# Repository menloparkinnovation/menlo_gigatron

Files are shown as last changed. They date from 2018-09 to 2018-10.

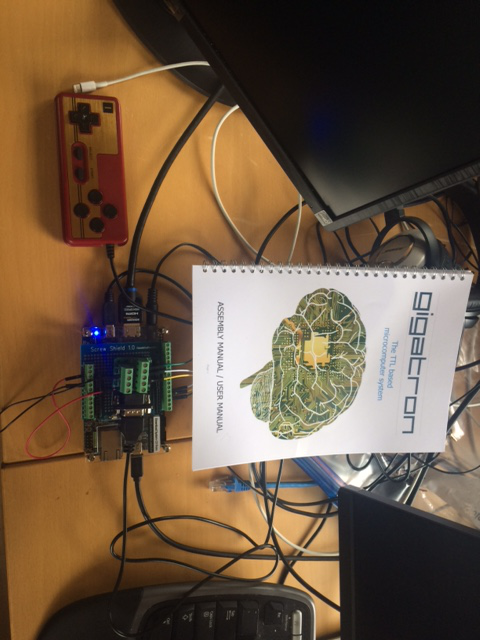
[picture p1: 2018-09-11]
pictures/hardware_wiring.jpg

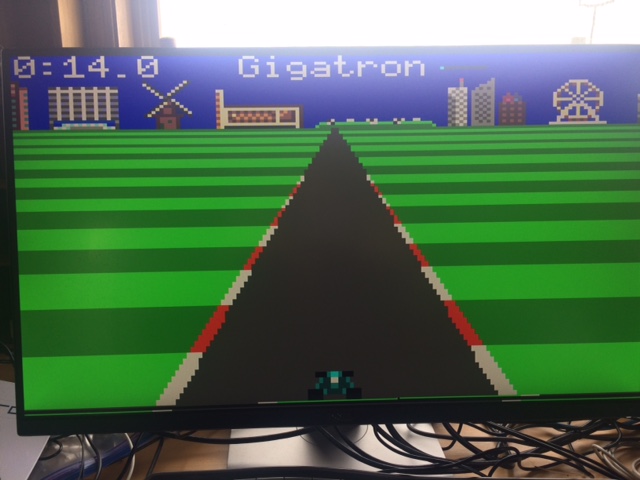
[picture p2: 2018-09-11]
pictures/racer_hires.jpg

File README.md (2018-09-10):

# menlo_gigatron
A System Verilog/FPGA implementation of the Gigatron project from https://gigatron.io/

# Building
Acquire a Terasic DE10-Nano FPGA development board from http://www.terasic.com.tw/cgi-bin/page/archive.pl?Language=English&CategoryNo=205&No=1046

It is about $130 retail, lower prices for education.

Other boards will work, but would need tweaking of the boards default "Shell" project that defines the resources of the board, and the specific version of the FPGA.

A Cyclone V SoC FPGA is used which as 41K logic elements and 5Mbits of block RAMS. It also has two 800Mhz ARM A9 processors with 1GB of RAM, and a couple of embedded Linux ports for both text mode and GUI. The SoC's are not currently used by this project at this time, but in the future will be used to manage downloads to the Gigatron and provide for an "EPROM emulator" for development.

Since its written in System Verilog, it could be ported to other FPGA's such as Xilinx.

The DE10-Nano user manual has instructions for installing the Altera/Intel Quartus II development software for the FPGA, which is available for free for educational and maker use. This software is required to compile your own FPGA bitstream from the Verilog sources.

# Running
The project implements an HDMI monitor interface with HDMI audio. The Gigatron's 4 bit VGA output and 4 bit sound is converted to 8 bit Truecolor at 640x480 on the monitor, with 16 bit I2S LPCM sound at 48Khz. The logic to do this actually exceeds the Gigatrons logic conumption by multiple times.

The Famicom game controller is connected with direct wires to the Arduino I/O pins on the DE10-Nano. The FPGA I/O ports have been configured to operate without the pull up or 68 ohm series resistors. I used a screw type DB9 male adapter and an Arduino "screw shield" for prototyping.

# Arduino IO Wiring
ARDUINO DIO2 - DB9 Pin 2 famicom_data (input)
ARDUINO DIO3 - DB9 Pin 4 famicom_pulse (output)
ARDUINO DIO4 - DB9 Pin 3 famicom_latch (output)
ARDUINO 5V   - DB9 Pin 6
ARDUINO GND  - DB9 Pin 8

# Future Work
Future work will provide an interface from the SoC's to the Gigatron to allow for development and debugging. This will include an emulation of the Arduino based loader for loading GTL programs into RAM, an EPROM emulator to allow Gigatron ROM development, and an ICE interface to read/write Gigatron registers and RAM, start/stop, etc. This would be available over character mode or VNC Linux running on the ARM SoC's.

The VGA framebuffer will be made available to the Linux, so an integration with a GUI Linux could be done within an X windows system with an application, and a merging of the Gigatron VGA handler in the project and the FPGA implementation of the Linux framebuffer.

# Gigatron Extensions
This provides a great platform for Gigatron extensions and experimentation. Additional registers, addressing modes, etc. I have thought of adding an extended addressing unit to it to allow it to access system memory outside of the Gigatron RAM so it can act as a soft processor. But this is challenged by having to manipulate 32 bit (or 64 bit addresses within a PCI bus) which involve many Gigatron processor load cycles. One solution would be to extend the register and instruction widths, but core Gigatron compatibility is still required. So we are back at 8080 -> 8086 -> 80286 -> 80386 -> ... all over again. One of the most fun aspects of the Gigatron project itself :-)

# Why did I do this?
I have an interest in FPGA based domain specific soft processors for my other project menlo_cnc which is an FPGA based CNC machine tool controller. Right now it operates similar to Gigatron as a simple microcoded hardware machine, but I want to add real time complex calculations such as curves onto the FPGA, and find that the interface to the ARM SoC's to be too slow. The Gigatron was used a learning experience in the implementation of a soft processor from scratch that could run existing software and tool chains, and do something useful and cool as well, such as play games.

I am a radio ham as well, and look forward to building an FPGA/SoC based implementation of a small portable SDR ham radio similar to, but an improvement on the excellent Elecraft KX3 (which I own). So I am interested in FPGA/SoC DSP techniques which is a leading area of SDR (Software Defined Radio).

On the professional side I am interested in Cloud applications of FPGA's at both the hyper-scale infrastructure, and Cloud applications such as "Big Data" and "AI". FPGA's have already revolutionized HFT (High Frequency Trading), and are emerging as a platform for drug discovery, etc. Soft processors on FPGA's are a solution to the slowing down of Moores law, which will have industry wide impact on the costs of computation. I anticipate future FPGA's to be tightly integrated with processors and to have complex programmable logic blocks similar to GPU's and DSP chips which allow a specific application domain to code its algorithms into the structure of the processor, with task specific data and operations as the "software".

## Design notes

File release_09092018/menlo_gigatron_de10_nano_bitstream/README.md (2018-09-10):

# FPGA Bitstream for DE10-Nano SoC and Cyclone V SoC FPGA.
Note that FPGA bitstreams are very specific to the board and FPGA version. If yours differs, a recompilation from the Verilog sources using Quartus II is required.

This bitstream may be loaded using the Altera loader JTAG loader utility without having to recompile the project.

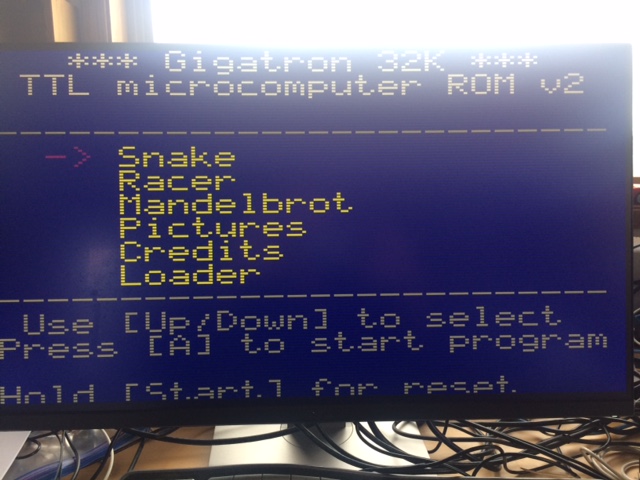
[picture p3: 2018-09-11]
pictures/signon.jpg

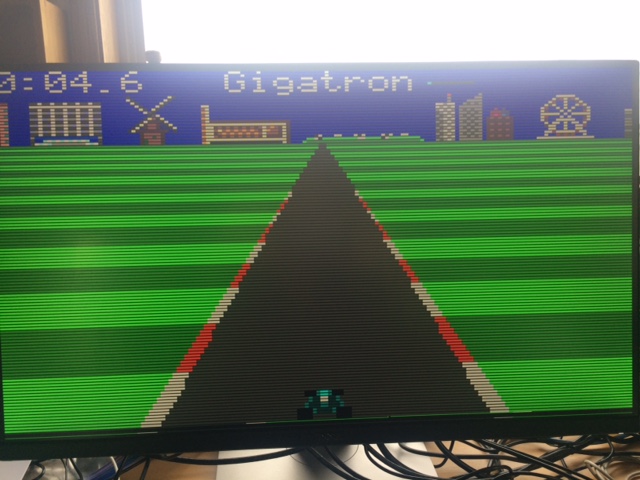
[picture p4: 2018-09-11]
pictures/racer_retro.jpg

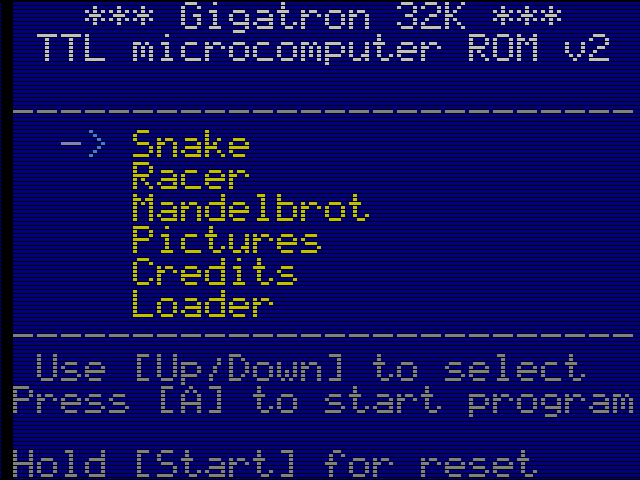
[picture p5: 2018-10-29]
menlo_gigatron_de10_nano/application_gigatron/first_full_screen.bmp

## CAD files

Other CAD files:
menlo_gigatron_de10_nano/db/stp1_auto_stripped.stp
menlo_gigatron_de10_nano/stp1.stp
archive/menlo_gigatron_de10_nano/db/stp1_auto_stripped.stp
archive/menlo_gigatron_de10_nano/stp1.stp

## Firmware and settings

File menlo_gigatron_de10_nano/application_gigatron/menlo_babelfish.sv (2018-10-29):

//
// TODO: 
//
// 10/10/2018
//
//  - remove loader_checksum as it operates on running_checksum now.
//

//
// See MENLO_COPYRIGHT.TXT for the copyright notice for this file.
//
// Use of this file is not allowed without the copyright notice present
// and re-distributed along with these files.
//

// set timescale for 1ns with 100ps precision.
`timescale 1ns / 100ps

//
// Gigatron BabelFish protocol implemented in System Verilog modeled
// on RDMA.
//
// Normally BabelFish runs on an Arduino, and its source code
// is in the Gigatron Rom Git project at:
//
// https://github.com/kervinck/gigatron-rom/Utils/BabelFish/babelfish.ino
//
// In this case BabelFish is implemented in System Verilog and is
// used by the Gigatron option ROM loader.
//
// Since the BabelFish loader protocol is essentially a version of RDMA
// (Remote Direct Memory Access), it will be modeled as such. This makes
// this Verilog code useful for other projects, such as network connected
// FPGA's for Software Defined Radio (SDR), machine tools (CNC), storage,
// and FPGA assisted high speed network communications between applications.
//
// FUTURE WORK:
//
//  Can generalize this RDMA communications handler by:
//
//  Add an IOMMU module to the output addresses. This will allow
//  address translation, validation, scatter/gather support, as
//  well as translations to program/VM virtual addresses based on
//  platform.
// 
//  Have the link level byte stream module interface be supplied to the
//  RDMA transmitter/receiver rather than contained within. This will allow
//  packet oriented protocols such as ethernet, UDP/IP/TCP to be readily
//  swapped in and out.
//
//  Have the RDMA framer modules interface be provided to the RDMA
//  transmitter/receiver. This allows other formats to be utilized
//  such as Infiniband or system TCP direct data placement.
//

module menlo_babelfish_rdma_transmitter
(
    input fpga_clock,      // FPGA 50Mhz clock
    input gigatron_clock,  // 6.25 Mhz Gigatron clock
    input reset,           // Reset when == 1

    // Timing input from the Gigatron
    input  famicom_pulse, // hsync_n
    input  famicom_latch, // vsync_n

    // Output to the Gigatron generated by this module
    output famicom_data,

    // Signals from user interface to select program to load
    input  request,  // true when user select load
    output request_ack, // true when transfer is complete.

    //
    // This provides access to the program loader option ROM.
    // rom_address == 0 is that start of the GT1 binary program
    // to load, as the invoker handles any translation from the base
    // 0 rom_address here to the offset into the option ROM is required.
    //
    output [15:0] rom_address,
    input [7:0] rom_data
  );

  reg reg_request_ack;
  assign request_ack = reg_request_ack;

  //
  // Current ROM address.
  //
  // This is updated as the state machine walks through the GT1 pages
  // in the option ROM loading them as a series of frames.
  //
  // It provides the base rom address to the frame loader for its
  // data to load. The frame loader will generate its own rom access
  // cycles as required. This register is only updated by this modules state
  // machine.
  //
  reg [15:0] reg_rom_address; // Data address of current program data being loaded.

  // Command to the page loader, and its ack
  reg reg_send_page_request;
  wire send_page_request_ack;

  //
  // The page loaders rom address generation is multiplexed based on
  // whether the page loader is active or not.
  //
  wire [15:0] page_loader_rom_address;

  //
  // This switches the rom address output between this module and
  // the page loader module based on when the page loader is active.
  //
  assign rom_address = (reg_send_page_request == 1'b1) ? page_loader_rom_address : reg_rom_address;

  //
  // The GT1 file loader advances through the ROM starting at address 0
  // reading the series of page headers (address, length), and invoking
  // the page loader for the pages data. The page loader will send the
  // page data as a series of one or more frames and return when done.
  //
  // The last page record in the GT1 file has a high address byte of 0
  // marking the end. The next bytes describe the start address for
  // the program, which is sent as a 0 length page to the page loader,
  // which is an indication to send a single 0 length frame with the
  // start address, as that is the Gigatron loader protocol.
  //

  //
  // At the start of a page send this is the GT1 page address and length.
  //
  // The address here is the remote Gigatron address and length to place
  // the GT1 page to.
  //
  reg [15:0] reg_current_page_remote_address;
  reg [8:0] reg_current_page_remote_length; // must handle 0 - 256 so its 9 bits.

  //
  // Page loader module instance.
  //

  menlo_babelfish_rdma_page_transmitter rdma_page_transmitter (
    .fpga_clock(fpga_clock),
    .gigatron_clock(gigatron_clock),
    .reset(reset),

     // pulse and latch are the input timing control signals.
    .famicom_pulse(famicom_pulse), // input
    .famicom_latch(famicom_latch), // input

    // Data is generated by the loader to be input to the Gigatron
    .famicom_data(famicom_data),  // output

     // These are the page request parameters
    .request(reg_send_page_request),       // input
    .request_ack(send_page_request_ack),   // output

    //
    // This address and length are the values to place in the loader frame
    // to represent the remote page address and length.
    //
    .request_page_remote_address(reg_current_page_remote_address), // input
    .request_page_remote_length(reg_current_page_remote_length),   // input

    //
    // This is the ROM address where the data for the page is.
    // It's length is the reg_current_page_remote_length.
    //
    .request_data_rom_address(reg_rom_address), // input

    // This gives the frame loader access to the option ROM when its active.
    .rom_address(page_loader_rom_address), // output
    .rom_data(rom_data)                   // input
  );

  //
  // GT1 file Loader States:
  //

  parameter[4:0]
    SEND_IDLE             = 5'b00000,

    SEND_FILE             = 5'b00001,

    // Getting Page parameters from the ROM
    PAGE_ADDRESS_HIGH     = 5'b00010,
    PAGE_ADDRESS_LOW      = 5'b00011,
    PAGE_LENGTH           = 5'b00100,

    // Sending a page as a series of frames.
    SENDING_PAGE          = 5'b00101,

    // Send the next page in the ROM.
    SEND_NEXT_PAGE        = 5'b00110,

    // Send a page of the file
    SEND_PAGE             = 5'b00111,

    // Getting the start address page from the ROM
    START_ADDRESS_HIGH    = 5'b01000,

    START_ADDRESS_LOW     = 5'b01001,

    SENDING_START_ADDRESS = 5'b01010,

    SENDING_PAGE_ACK      = 5'b01011,

    // Waiting for the invoker to deassert request and finish.
    FINALIZE              = 5'b11111;

  // Loader state machine
  reg [4:0] loader_state;
  reg [4:0] loader_next_state;
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

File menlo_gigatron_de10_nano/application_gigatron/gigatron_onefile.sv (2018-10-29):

//`define EDGE_MARKERS 1

//
// See MENLO_COPYRIGHT.TXT for the copyright notice for this file.
//
// Use of this file is not allowed without the copyright notice present
// and re-distributed along with these files.
//

// set timescale for 1ns with 100ps precision.
`timescale 1ns / 100ps

//
// 07/04/2018
//
// One file implementation of the Gigatron in System Verilog.
//
// Inspired by the one file C program gtemu.c and the simple
// block diagram.
//
// Why Gigatron?
//
// It's a simple processor. It does not take up much space on an FPGA
// so it can be used to implement more complex state machines better
// represented in a processor than Verilog for access by software trained
// engineers.
//
// Since its simple, it provides a great introduction to the implemention
// of soft-procesors on an FPGA.
//
// Since it uses low resources, you can implement multiple of them dedicated
// to specific tasks in parallel. So you effectively have a "multi-core"
// processor setup.
//
// Since its simple, its easy to customize for specific tasks such as
// memory block move instructions, protocol processing instructions, and
// other "instructions" connected directly to FPGA logic expressed in Verilog.
//
// Due to its simple, low resource design it can be used in hybrid architectures
// such as hyperthreading in which longer memory latencies (such as over
// a PCIe bus, a DRAM, etc.) can be "hidden" from multiple virtual execution
// units Tera computer or SPARC hyperthreading style.
//
// 6.25 Mhz Clock: This is required to execute existing Gigatron software
// correctly since timing loops are embedded in the code as per practice
// in the 8 bit world. For embedded situations with new code you can use
// the clock frequency of your FPGA, which is 50Mhz on the Altera Cyclone V
// used in the Terasic DE10-Standard and DE10-Nano boards.
//

//
// The top level Gigatron module integrates its EEPROM, RAM,
// I/O, and system control signals.
//
// This allows the components to be replaced or repurposed as needed.
//

module Gigatron_BlinkenLights
(
    input [7:0] ext_io_in,

    // Generated BlinkenLights signals
    output led5, // extended_output_port bit 0
    output led6, // "" bit 1
    output led7, // "" bit 2
    output led8  // "" bit 3
);

  assign led5 = ext_io_in[0:0];
  assign led6 = ext_io_in[1:1];
  assign led7 = ext_io_in[2:2];
  assign led8 = ext_io_in[3:3];

endmodule // Gigatron_BlinkenLights

//
// HDMI audio
//
// Outputs mono 16 bit LPCM (Linear Pulse Code Modulation) which is
// the audio format used by HDMI and CD audio and represents the
// waveform samples in two's complement.
//
// Digital Volume Control
//
// The I2S audio has a 16 bit twos complement magnitude.
//
// The Gigatron audio handler converts the Gigatrons 4 bit zero
// based sine wave quantized pulses into a 4 bit two's complement
// representation for the positive and negative portions of the
// audio sine wave.
//
// If this magnitude is shifted to the highest bits, the highest
// signal level, or loudest sound is generated.
//
// Shifting the magnitude down will lower the volume as they represent
// smaller audio voltage/power output.
//
// Normally I2S audio is designed for smaller bit transmitters such
// as the Gigatron to larger bit receivers to send MSB first on
// the highest bits. This allows the receiver to detect how many
// bits are actually sent, and compensate the volume range internally.
//
// In this case we are not announcing to the standard HDMI I2S audio
// that we are only a 4 bit sender (if that is even supported), but
// that we are a standard 16 bit magnitude sender.
//
// As a result we are responsible for any magnitude shift/adjustment
// to control audio output volume to the monitor. So a digital
//  "volume control" is implemented.
//
// The digital volume control has a range from 0 - 11
// and is represented with a 4 bit value. This represents
// the bit shift of the magnitude of the 4 bit Gigatron
// audio (after conversion to two's complement) within
// the 16 bit magnitude range of the supported HDMI audio.
//
// Each change in volume is a power of two, which lines
// up with actual hearing response and "audio taper" volume
// controls in the analog world. A finer control could be
// developed, but this range is fine for a gaming machine
// used through speakers.
//
// And in case you want to use this for a rock band amplifier,
// its a useful feature to go to 11...
//
// https://en.wikipedia.org/wiki/Spinal_Tap_(band)
// https://www.youtube.com/watch?v=KOO5S4vxi0o
//
module Gigatron_Audio_Handler
(
    input fpga_clock,
    input gigatron_clock,
    input reset,
    input [3:0] digital_volume_control,
    input [7:0] ext_io_in, // Gigatron Extended I/O port
    output [15:0] output_audio_dac
    );

  wire [3:0] sample;

  //
  // Gigatron extended_output_port bits 7-4
  //
  // This is a real time 4 bit audio pass through from the Gigatron.
  //
  // It represents a software generated audio wave form with
  // range from 0 - 15. The entire audio signawave is represented
  // within this range with 0 being the most negative magnitude value.
  //

  assign sample = ext_io_in[7:4];

  //
  // The Gigatron audio is 4 bits, from 0 - 15. This represents analog voltage
  // levels into a resistor network, with RC low and high pass filters.
  //
  // The zero crossing center point of a sine wave would be half way through
  // the values, or 4'b0111.
  //
  // LPCM (Linear Pulse Code Modulation) which is the audio format used
  // by HDMI and CD audio represents the waveform samples in two's complement.
  //
  // Positive numbers represent the positive portion of the sine wave
  // and two's complement negative numbers represent the negative portion
  // of the wave.
  //
  // So we translate these signals here from a 4 bit 0 based analog signal
  // to a 4 bit two's complement one.
  //
  // Note: The I2S audio interface standard used by HDMI operates with
  // MSB first so that shorter bit length samples are read with zero fill
  // in the LSB bits. So these 4 bit Gigatron audio samples will become the
  // high order bits [15:12] and the low order bits [11:0] will be zero's.
  //

  reg [3:0] translated;

  always @* begin
    output_audio_dac = translated << digital_volume_control;
  end

  //
  // Translates the 0 - 15 analog range as 4 bit two's complement.
  //

  always@(sample) begin

      case (sample)

	//
	// Positive portion of the sine wave above the zero crossing.
	//
	4'b0000: translated = 4'b0000; // 0
	4'b0001: translated = 4'b0001; // +1
	4'b0010: translated = 4'b0010; // +2
	4'b0011: translated = 4'b0011; // +3
	4'b0100: translated = 4'b0100; // +4
	4'b0101: translated = 4'b0101; // +5
	4'b0110: translated = 4'b0110; // +6
	4'b0111: translated = 4'b0111; // +7
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

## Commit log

2018-10-29 Convert to silicon_shell framework. Add Verilog implementation for BabelFish (still debugging). Add VGA overlay sprite support (under development)
    [stp1.stp, stp1_auto_stripped.stp]
2018-10-29 make git remove the files
    [stp1.stp, stp1_auto_stripped.stp]
2018-10-29 Convert to silicon shell framework. Implement Verilog version of BabelFish program loader (debugging). Add VGA overlay sprite support with text (under development)
    [stp1.stp, stp1_auto_stripped.stp]
